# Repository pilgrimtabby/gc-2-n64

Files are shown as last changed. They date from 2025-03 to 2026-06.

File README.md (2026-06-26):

# gc-2-n64

PCB and custom firmware for a gamecube to N64 controller adapter. The firmware is an updated version of [Raphaël Assenat's](https://github.com/raphnet)'s v2.1 gc_to_n64 software ([here](https://www.raphnet.net/electronique/gc_to_n64/index_en.php), see also [here](https://github.com/raphnet/gc_to_n64)). It implements two major new features: an input viewer (from the USB port on the Arduino, compatible with RetroSpy) and a notch calibrator (heavily adapted from [Zenith Labs' algorithm](https://github.com/ZenithControlLabs/Zenith_FW)). It also allows many more degrees of flexibility when configuring soft triggers -- triggers can be mapped at 5% press, 10% press, 15% press, and so on until 100%. 

I have also included a file ([generate-button-map.html](generate-button-map.html)) that allows users to generate custom button mappings locally. Download the file and run it in a web browser to use it.

The PCB design was heavily inspired by and drawn from [SuperSpongo's DIY adapter design](https://circuit-board.de/forum/index.php/Thread/28130-Raphnets-GameCube-Controller-to-N64-Adapter-v2/). And as mentioned before, the credit for 99% of the ideas and code goes to Raphnet, Zenith Labs, and SuperSpongo. Because I modified firmware licensed under the GPLv3 License, the code in src/ is licensed under the GPLv3 License. The PCB is licensed under the MIT license.

# Instructions

## Assembly

This project requires an Arduino Nano (though I believe any Arduino running at 5V/16MHz should work) and a DC-DC 2V-24V to 5V-28V step-up converter (the N64 provides 3.3V and we need 5V to power the Gamecube controller). You'll also need a 1KΩ resistor (R4 on the schematic), two 22Ω resistors (R1 and R3), a 220Ω resistor (R2), an LED (D1), a male N64 controller port / cable, and a female Gamecube port / cable.

(Note: If you want to modify the KiCad files, you'll need the schematic and footprint files for the boost converter found [here](pcb/kicad/gc_2_n64/boost-converter-files)).

The step-up converter needs to be calibrated to output exactly 5V when receiving 3.3V. You can do this by connecting it to a 3.3V source, such as the N64, then turning the screw on the side until the output is correct.

When soldering the wires from the Gamecube in and N64 out, follow the labels in this image:

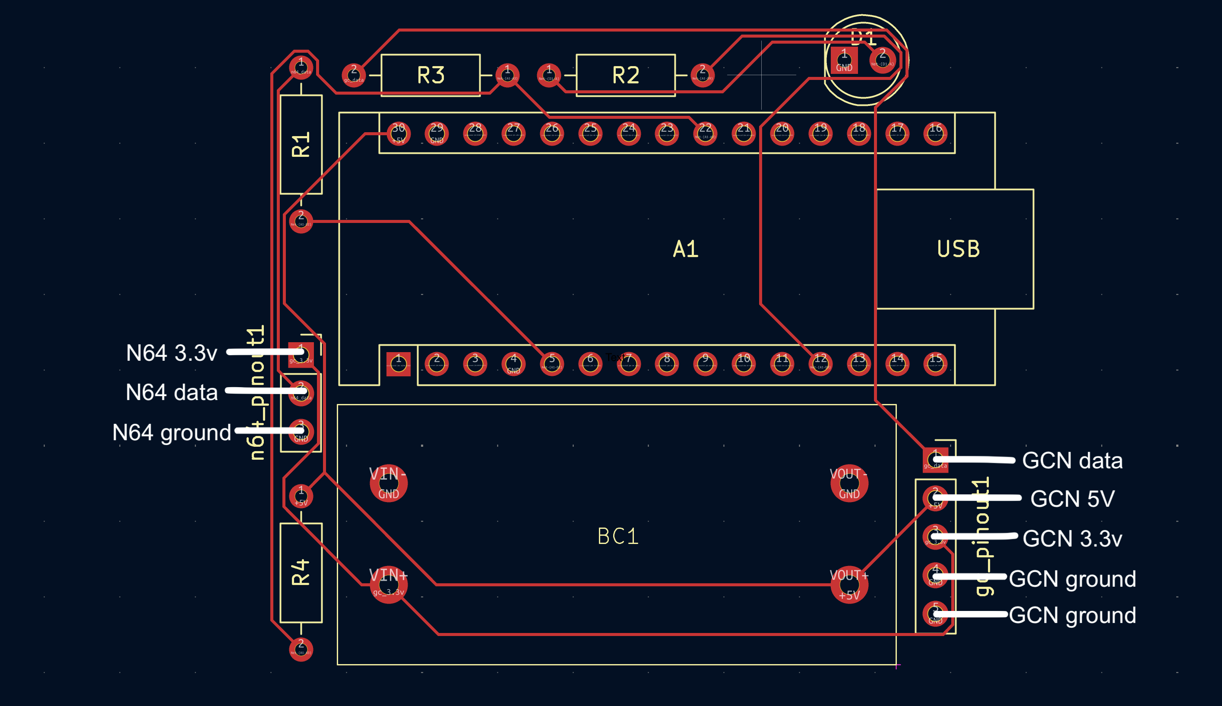
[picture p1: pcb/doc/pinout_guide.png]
Pinout guide


For the N64 pinout, see [here](https://consolemods.org/wiki/N64:Connector_Pinouts). Generally, the red cable is power, white is data, and black is ground.

Gamecube pinouts are all over the place depending on which vendor you purchase from. The best resource I am aware of is [this one](https://docs.google.com/spreadsheets/d/1X-F21F838uQRCuYsc7nQoAv6I2dchvXtBSNTf-ZOc9M).

## Example of Finished Project

The assembled PCB:

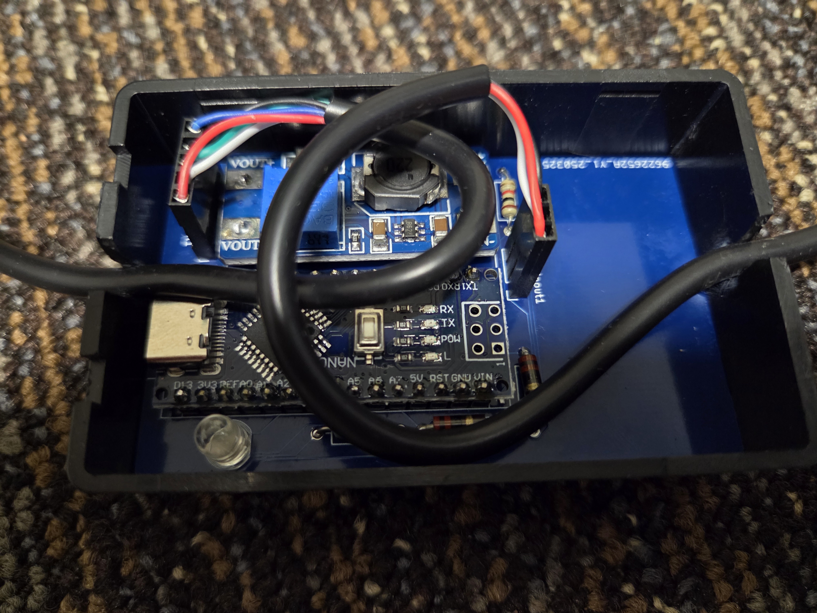
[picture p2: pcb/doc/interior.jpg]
Assembled PCB


The LED indicator:

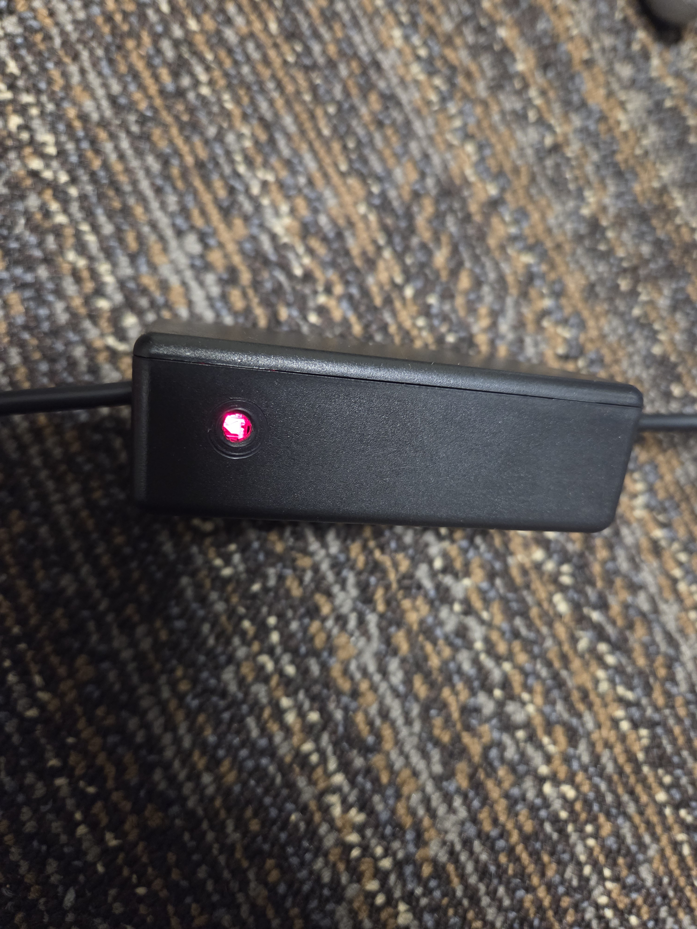
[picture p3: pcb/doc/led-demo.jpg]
LED light


Final product:

Completed project

## Flashing

To flash the Arduino, you will need [avrdude](https://github.com/avrdudes/avrdude) and the latest gc_2_n64.hex hexfile (see [Releases](https://github.com/pilgrimtabby/gc-2-n64/releases)). I successfully flashed the firmware using this command:

```
/path/to/avrdude /path/to/avrdude.conf -v -V -p atmega328p -c arduino -P /path/to/serial/port -b115200 -D -U flash:w:/path/to/hexfile
```

The path to the serial port can be obtained from the [Arduino IDE](https://www.arduino.cc/en/software/).

For detailed usage of the firmware, see Raphnet's [instructions](https://www.raphnet.net/electronique/gc_to_n64/index_en.php#8). To use the new input display, just connect the Arduino to your PC via the Arduino's USB port. To use the notch calibrator, hold down the start button for 8 seconds to access the menu, then press R, then press Y. Leave the control stick at neutral and press A. The LED will blink. Do the same thing for the eight notches, starting with straight up and moving clockwise around the gate. The mapping will be saved between sessions. To clear it, press A in the R menu.

Questions, issues, PRs, etc. more than welcome!

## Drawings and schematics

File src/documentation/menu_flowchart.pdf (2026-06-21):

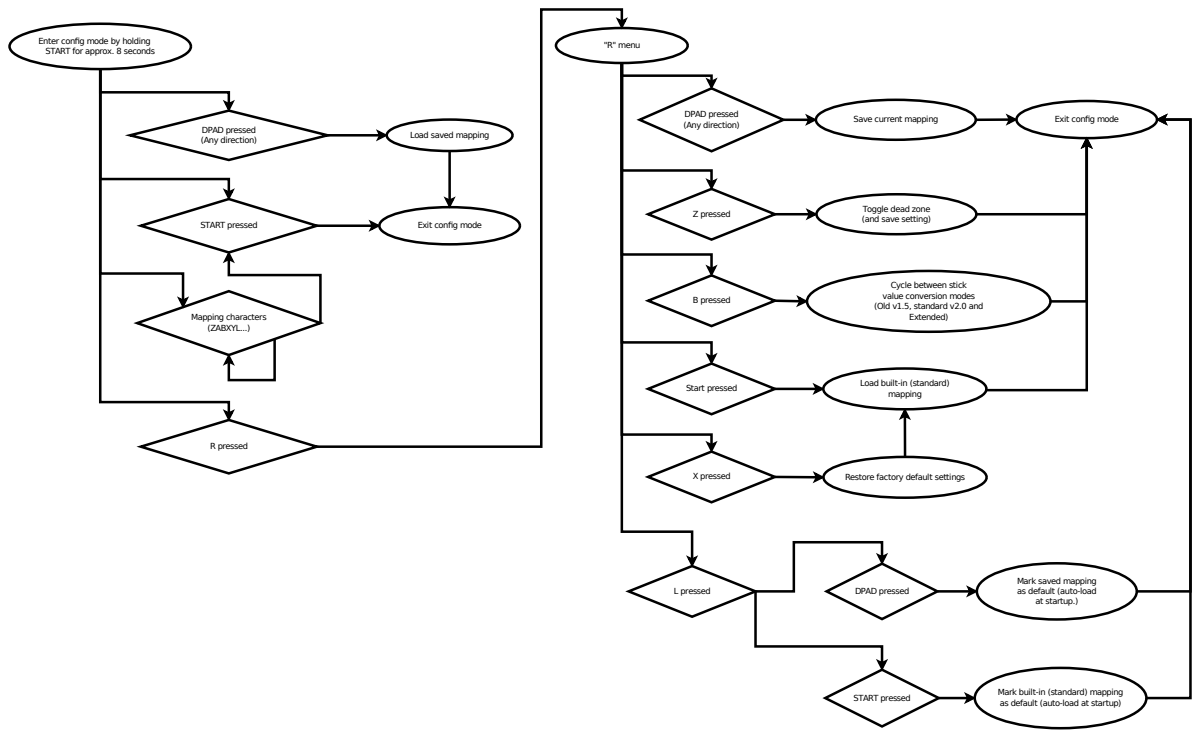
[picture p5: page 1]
DPAD pressed; (Any direction); Load saved mapping; START pressed; Exit config mode; Mapping characters (ZABXYL...); R pressed; "R" menu; Save current mapping; Z pressed; Toggle dead zone; Start pressed; Load built-in (standard); mapping; L pressed; B pressed; Extended); X pressed; Restore factory default settings

Enter config mode by holding
START for approx. 8 seconds

(and save setting)

Cycle between stick
value conversion modes
(Old v1.5, standard v2.0 and

Mark saved mapping
as default (auto-load
at startup.)

Mark built-in (standard) mapping
as default (auto-load at startup)

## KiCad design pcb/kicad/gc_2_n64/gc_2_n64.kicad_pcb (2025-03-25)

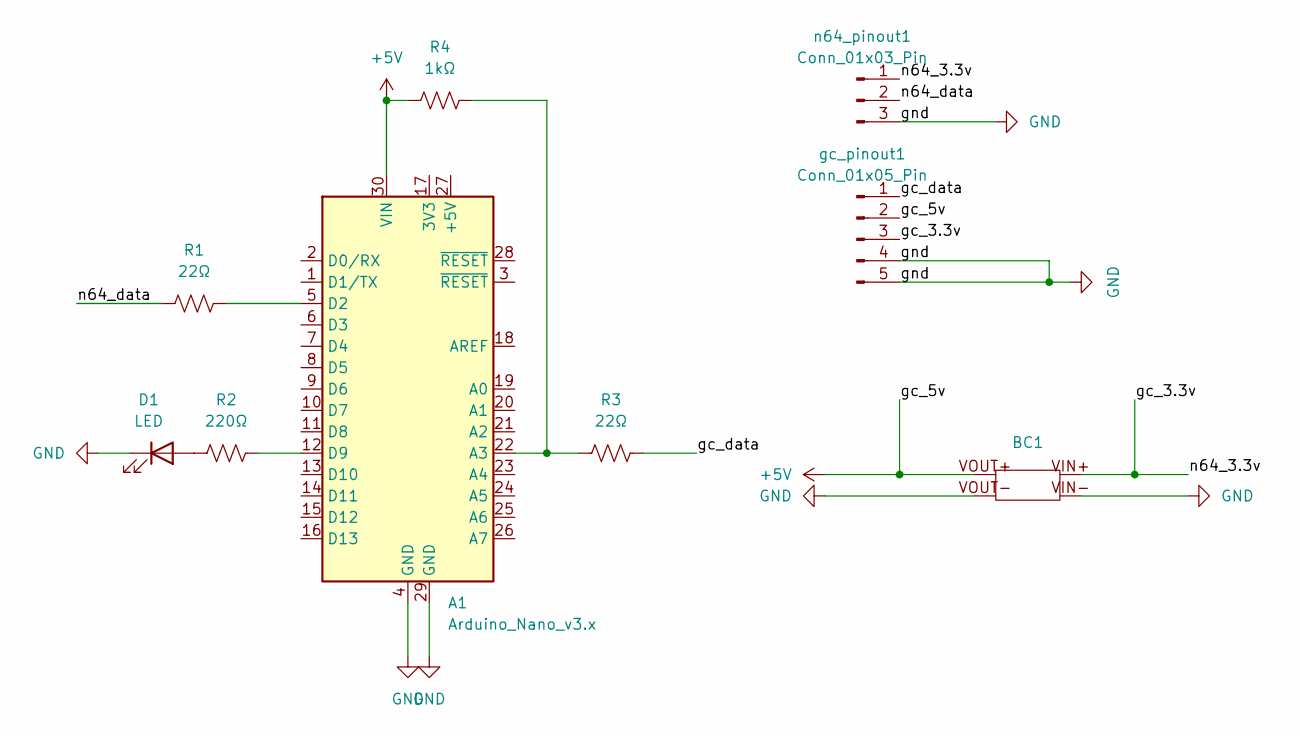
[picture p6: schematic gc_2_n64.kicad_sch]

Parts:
A1: Arduino_Nano_v3.x; Arduino_Nano
BC1: BC_boost_converter_MT3608_breakout
D1: LED; LED_D5.0mm
R1, R3: 22Ω; R_Axial_DIN0207_L6.3mm_D2.5mm_P10.16mm_Horizontal
R2: 220Ω; R_Axial_DIN0207_L6.3mm_D2.5mm_P10.16mm_Horizontal
R4: 1kΩ; R_Axial_DIN0207_L6.3mm_D2.5mm_P10.16mm_Horizontal
gc_pinout1: Conn_01x05_Pin; PinSocket_1x05_P2.54mm_Vertical
n64_pinout1: Conn_01x03_Pin; PinSocket_1x03_P2.54mm_Vertical

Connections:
+5V: A1.30 (VIN), BC1.VOUT+, R4.1, gc_pinout1.2
/gc_3.3v: BC1.VIN+, gc_pinout1.3, n64_pinout1.1
/gc_data: R3.2, gc_pinout1.1
/n64_data: R1.1, n64_pinout1.2
GND: A1.4 (GND), A1.29 (GND), BC1.VIN-, BC1.VOUT-, D1.1 (K), gc_pinout1.4, gc_pinout1.5, n64_pinout1.3
unnamed: A1.22 (A3), R3.1, R4.2
unnamed: A1.5 (D2), R1.2
unnamed: A1.12 (D9), R2.2
unnamed: D1.2 (A), R2.1

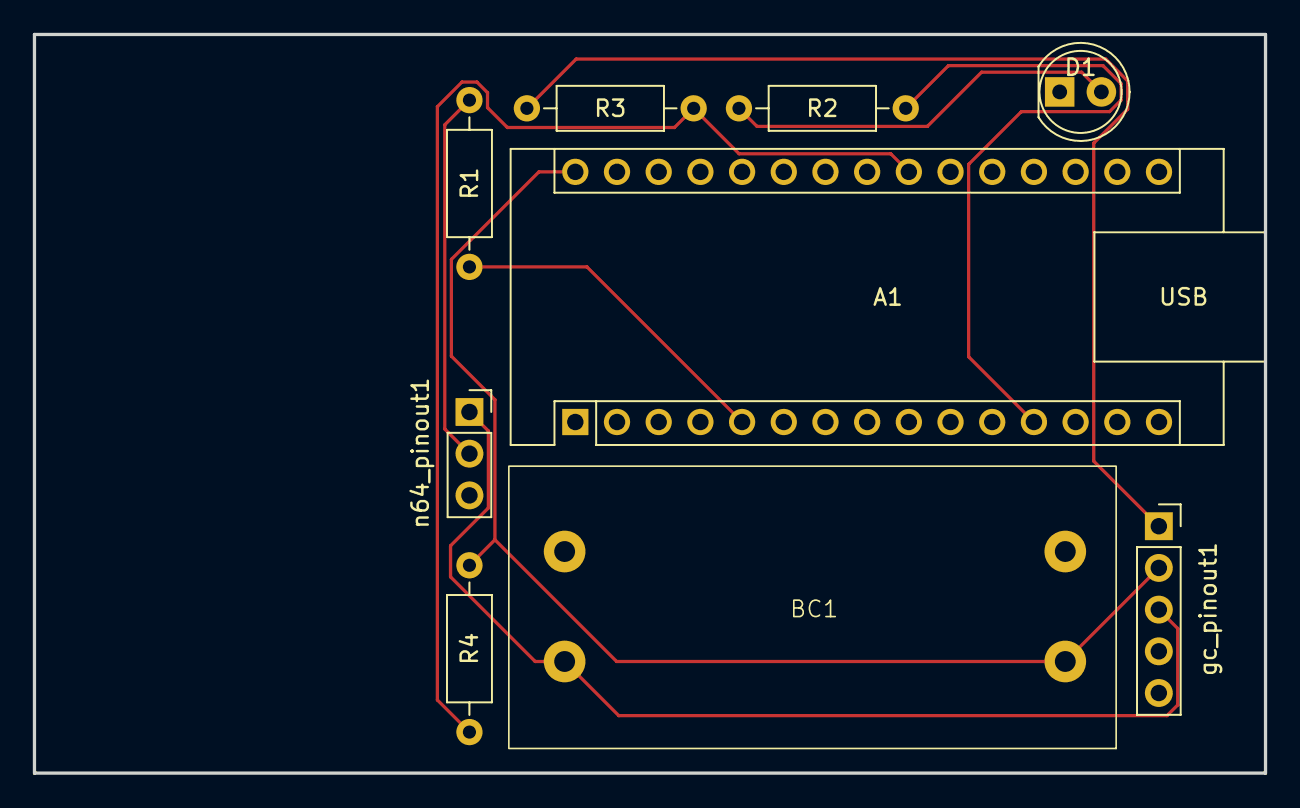
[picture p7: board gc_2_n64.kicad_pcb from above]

Board: 2 copper layers, 75.0 x 45.0 mm, 9 parts (0 on the bottom side), 9 nets.

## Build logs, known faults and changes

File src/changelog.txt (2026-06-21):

June 21, 2026: Pilgrim Tabby Version 1.0
    - Add notch calibration feature in R-menu
    - Add input display via Arduino's USB-C port, compatible with RetroSpy

April 9, 2017 : Version 2.1
    - Add a new conversion mode for Joystick values: Extended (where Gamecube
  	  values are forwarded to the N64 without transformations)
    - Set lock bits to protect bootloader from erasure

October 10, 2015 : Version 2.0
    - Now built for Atmega168 by default. Old makefile for Atmega8 is still available.
	- Add a bootloader (Atmega168 only) for software updates.
    - N64 communication code improvements (more reliable. Fixes the F-Zero X bug!)
    - Improved joystick value conversion (the old behaviour is available via a menu option).
	- Add a reset to factory defaults function.
	- Add mapping load/save through the N64 interface support
	- Add visual buzzer (simple LED) support. (default for Atmega168)
    - Created a flowchart of the menu

March 15, 2015 : Version 1.5.1
    - New fuse values to enable brown out detector. Fixes
	  the issue of random loss of mappings.

February 7, 2015 : Version 1.5
    - Add a feature to select the default mapping at startup.
	- Minor updates for compilation with recent toolchain.

May 5, 2013 : Version 1.4
    - Tighter timing in the N64 interrupt handler. The adapter now
	  starts answering much faster. This appears to fix F-Zero X.
	  (Never seen a game picky and *buggy like that)
	  * Disconnect even a standard controller and say goodbye
	  to your race. Connecting the controller back does not work. Right,
	  no reason to do that. But if the controller fails to answer only
	  one poll request, it's game over...
    - Fix an ED64 menu "freeze" bug
	- Improve the Wavebird neutral position

April 27, 2013 : Version 1.3.1
    - Fixed a bug when mapping the main joystick to buttons.
	  The up[18]/down[19] and left[20]/right[21] directions were inverted.
    - Fixed a bug when entering a new mapping code where the unchanged
 	  parts of the previously active mapping remained in effect.

March 2, 2013 : Version 1.3
    - Added a joystick deadzone feature (default OFF). To enable,
	or disable if previously enabled, hold START until your hear the 5
	beeps, fully press and release R, the press Z. Wait a few moments
	for the final beeps. The setting is stored in the adapter, no need
	 to repeat after each power up.

February 12, 2013 : Version 1.2.2 - Bug fixes and minor features
    - The analog L and R sliders are now unmapped by default.
    - Beep on read errors (when disconnecting controller).
    - Beep once at powerup.

July 31, 2012 : Version 1.2.1 - Quick bug fix
    - Reset the read failure counter on success. Otherwise the failures
	  accumulate and eventually forces a recalibration, potentially in-game.

July 30, 2012 : Version 1.2 - Bug fixes and maintenance

	- Auto-calibration is now done each time a new controller
	  is connected, which means controllers can be swapped at runtime.
	- The above makes the Wavebird work properly again (was broken in v1.1!)
	- At powerup, the adapter waits for a Gamecube controller.
	- A newer version of the Gamecube communication code (ported from my
	  N64/Gamecube to USB project) is now in place.

January 25, 2011 : Version 1.1. Compatiblity fixes:

    - Auto-calibration of the gamecube joystick at powerup fixes
	  compatiblity issues with controllers that are not *perfectly*
	  centered.

	- Better conversion from Gamecube axis values to N64 values. This
	  fixes issues with some game/controllers where, for instance,
	  the character would not run at full speed.

	Note: The maximum axis values and corner angles closely approximates
    those from a N64 Hori mini pad.

August 10, 2011 : Version 1.0. Initial relase.

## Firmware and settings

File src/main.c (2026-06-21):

/*  GC to N64 : Gamecube controller to N64 adapter firmware
    Copyright (C) 2011-2017  Raphael Assenat <raph@raphnet.net>

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
    You should have received a copy of the GNU General Public License
    along with this program.  If not, see <http://www.gnu.org/licenses/>.
*/

// Modified by Pilgrim Tabby (2026) to add new mapping options

#include <stdio.h>
#include <string.h>
#include <stdlib.h>
#include <util/delay.h>
#include <avr/io.h>
#include <avr/interrupt.h>
#include <avr/pgmspace.h>
#include "main.h"
#include "buzzer.h"
#include "timer0.h"
#include "lut.h"
#include "menu.h"

#include "gamecube.h"

//#include "gc_offsets.h"
//#include "n64_offsets.h"

#include "n64_isr.h"
#include "sync.h"
#include "mapper.h"
#include "gamecube_mapping.h"
#include "n64_mapping.h"
#include "compat.h"
#include "eeprom.h"
#include "retrospy.h"
#include "notch_cal.h"

/* After this many read failures in a row, consider the controller
 * gone and wait for a new one. (whose first read will be considered
 * the origin) */
#define READ_FAIL_LIMIT		20

#define DEBUG_LOW()		do { PORTD &= ~(1); } while(0)
#define DEBUG_HIGH()	do { PORTD |= 1; } while(0)

#ifdef AT168_COMPATIBLE
/* This is just a constant that will be in flash. The update tool will search
 * the hexfile for this sequence. In not found, update won't take place. The
 * goal is to prevent temporary bricking due to users using the wrong .hex.   */
const char signature[] PROGMEM = "41d938a8-6f8a-11e5-a45e-001bfca3c593";

/* This marker is used by the bootloader to protect against partial programming.
 * Since programming is done with increasing addresses, if it is interrupted, this
 * sequence at the end will be missing if interrupted. */
const char endmarker[4] __attribute__((section(".endmarker")))  = { 0x12, 0x34, 0x56, 0x78 };
#endif

void enter_bootloader(void);

Gamepad *g_gcpad;
unsigned char gc_report[GC_REPORT_SIZE];

// When non-zero, triggers saving the current mapping to specified slot
// in the main loop.
static volatile unsigned char g_todo_save_mapping;

struct mapping_entry current_mapping[MAP_GC_NONE + 2];

struct mapping_entry gamecube_to_n64_default_mapping[MAP_GC_NONE + 2] = {
	{ MAP_GC_BTN_A,				MAP_N64_BTN_A },
	{ MAP_GC_BTN_B,				MAP_N64_BTN_B },
	{ MAP_GC_BTN_Z,				MAP_N64_BTN_Z },
	{ MAP_GC_BTN_START,			MAP_N64_BTN_START },
	{ MAP_GC_BTN_L,				MAP_N64_BTN_L },
	{ MAP_GC_BTN_R,				MAP_N64_BTN_R },
	{ MAP_GC_AXB_C_UP,			MAP_N64_BTN_C_UP },
	{ MAP_GC_AXB_C_DOWN,		MAP_N64_BTN_C_DOWN },
	{ MAP_GC_AXB_C_LEFT,		MAP_N64_BTN_C_LEFT },
	{ MAP_GC_AXB_C_RIGHT,		MAP_N64_BTN_C_RIGHT },
	{ MAP_GC_BTN_DPAD_UP,		MAP_N64_BTN_DPAD_UP },
	{ MAP_GC_BTN_DPAD_DOWN,		MAP_N64_BTN_DPAD_DOWN },
	{ MAP_GC_BTN_DPAD_LEFT,		MAP_N64_BTN_DPAD_LEFT },
	{ MAP_GC_BTN_DPAD_RIGHT,	MAP_N64_BTN_DPAD_RIGHT },
	{ MAP_GC_AXIS_LEFT_RIGHT,	MAP_N64_AXIS_LEFT_RIGHT },
	{ MAP_GC_AXIS_UP_DOWN,		MAP_N64_AXIS_UP_DOWN },
	{ MAP_GC_BTN_X,				MAP_N64_NONE },
	{ MAP_GC_BTN_Y,				MAP_N64_NONE },
	{ MAP_GC_AXB_JOY_UP,		MAP_N64_NONE },
	{ MAP_GC_AXB_JOY_DOWN,		MAP_N64_NONE },
	{ MAP_GC_AXB_JOY_LEFT,		MAP_N64_NONE },
	{ MAP_GC_AXB_JOY_RIGHT,		MAP_N64_NONE },
	{ MAP_GC_AXIS_C_LEFT_RIGHT,	MAP_N64_NONE },
	{ MAP_GC_AXIS_C_UP_DOWN,	MAP_N64_NONE },

	/* These slots must exist (even pointing at MAP_N64_NONE) for
	 * mapper_change_mapping_entry() to find and overwrite them via
	 * the menu code system. It only updates existing entries, it
	 * never inserts new ones. */
	{ MAP_GC_L_05,  MAP_N64_NONE },
	{ MAP_GC_L_10,  MAP_N64_NONE },
	{ MAP_GC_L_15,  MAP_N64_NONE },
	{ MAP_GC_L_20,  MAP_N64_NONE },
	{ MAP_GC_L_25,  MAP_N64_NONE },
	{ MAP_GC_L_30,  MAP_N64_NONE },
	{ MAP_GC_L_35,  MAP_N64_NONE },
	{ MAP_GC_L_40,  MAP_N64_NONE },
	{ MAP_GC_L_45,  MAP_N64_NONE },
	{ MAP_GC_L_50,  MAP_N64_NONE },
	{ MAP_GC_L_55,  MAP_N64_NONE },
	{ MAP_GC_L_60,  MAP_N64_NONE },
	{ MAP_GC_L_65,  MAP_N64_NONE },
	{ MAP_GC_L_70,  MAP_N64_NONE },
	{ MAP_GC_L_75,  MAP_N64_NONE },
	{ MAP_GC_L_80,  MAP_N64_NONE },
	{ MAP_GC_L_85,  MAP_N64_NONE },
	{ MAP_GC_L_90,  MAP_N64_NONE },
	{ MAP_GC_L_95,  MAP_N64_NONE },
	{ MAP_GC_L_100, MAP_N64_NONE },

	{ MAP_GC_R_05,  MAP_N64_NONE },
	{ MAP_GC_R_10,  MAP_N64_NONE },
	{ MAP_GC_R_15,  MAP_N64_NONE },
	{ MAP_GC_R_20,  MAP_N64_NONE },
	{ MAP_GC_R_25,  MAP_N64_NONE },
	{ MAP_GC_R_30,  MAP_N64_NONE },
	{ MAP_GC_R_35,  MAP_N64_NONE },
	{ MAP_GC_R_40,  MAP_N64_NONE },
	{ MAP_GC_R_45,  MAP_N64_NONE },
	{ MAP_GC_R_50,  MAP_N64_NONE },
	{ MAP_GC_R_55,  MAP_N64_NONE },
	{ MAP_GC_R_60,  MAP_N64_NONE },
	{ MAP_GC_R_65,  MAP_N64_NONE },
	{ MAP_GC_R_70,  MAP_N64_NONE },
	{ MAP_GC_R_75,  MAP_N64_NONE },
	{ MAP_GC_R_80,  MAP_N64_NONE },
	{ MAP_GC_R_85,  MAP_N64_NONE },
	{ MAP_GC_R_90,  MAP_N64_NONE },
	{ MAP_GC_R_95,  MAP_N64_NONE },
	{ MAP_GC_R_100, MAP_N64_NONE },

	{ MAP_GC_NONE,				MAP_N64_NONE },
	{ -1, -1 }, // terminator
};

void saveCurrentMappingTo(int id)
{
	if (id >= 1 && id <= 4) {
		memcpy( g_eeprom_data.appdata + (sizeof(current_mapping) * (id-1)), current_mapping, sizeof(current_mapping));
		eeprom_commit();
	}
}

int loadMappingId(int id)
{
	unsigned char *mapping_pointer;

	// Always start from default mapping
	memcpy(current_mapping, gamecube_to_n64_default_mapping, sizeof(current_mapping));

	switch(id)
	{
		default:
		case 0:
			// default mapping used.
			break;

		case 1:
		case 2:
		case 3:
		case 4:
			mapping_pointer = g_eeprom_data.appdata + (sizeof(current_mapping) * (id-1));
			if (mapping_pointer[0] == 0xff) {
				// Terminator at the beginning? Empty slot!
				return -1;
			}
			memcpy(current_mapping, mapping_pointer, sizeof(current_mapping));
	}
	return 0;
}


int domenu(struct mapping_controller_unit *gcs)
{
	static int start_seconds = 0;

	if (gcs[MAP_GC_BTN_START].value) 
	{
		if (timerIsOver()) {
			start_seconds++;
			if (start_seconds > 5) {
				menumain();
				return 1;
			}
		} 
	}
	else {
		start_seconds = 0;
	}
	return 0;
}
void byteTo8Bytes(unsigned char val, unsigned char volatile *dst)
{
	unsigned char c = 0x80;

	do {
		*dst = val & c;
		dst++;
		c >>= 1;
	} while(c);
}


#define IS_ACTIVE(a) ((a).value != (a).def)

unsigned char long_command_handler(unsigned char len)
{
	if (len >= 2)
	{
		if (g_n64_buf[0] == 'R') {
			switch (g_n64_buf[1]) {
				case 0x00: // echo
					return len;

				case 0x01: // Get info
					memset((void*)g_n64_buf, 0, sizeof(g_n64_buf));
					g_n64_buf[0] = 0; // Isbootloader? No.
					g_n64_buf[1] = g_eeprom_data.defmap;
					g_n64_buf[2] = g_eeprom_data.deadzone_enabled;
					g_n64_buf[3] = g_eeprom_data.old_v1_5_conversion;
					g_n64_buf[4] = g_eeprom_data.conversion_mode;
#ifdef AT168_COMPATIBLE
					g_n64_buf[9] = 1; // Upgradable
#endif
					strcpy((void*)(g_n64_buf+10), VERSION_STR);
					return 10 + strlen(VERSION_STR) + 1;

				case 0x02: // Get mapping
					if (len >= 4) {
						int id = g_n64_buf[2];
						int chunk = g_n64_buf[3];
						unsigned short mapping_size = sizeof(current_mapping);

						if (id >= 0 && id <= 4) {
							unsigned char *mapping_pointer;

							if (id) {
								mapping_pointer = g_eeprom_data.appdata + (sizeof(current_mapping) * (id-1));
							} else {
								mapping_pointer = (unsigned char*)&current_mapping[0];
							}

							if (chunk == 0) {
                                g_n64_buf[0] = mapping_size & 0xff;
                                return 1;
                            } else {
                                int offset = (chunk - 1) * 32;
                                if (offset >= mapping_size) return 0;
                                
                                int to_copy = mapping_size - offset;
                                if (to_copy > 32) to_copy = 32;
                                
                                memcpy((void*)g_n64_buf, mapping_pointer + offset, to_copy);
                                return to_copy;
                            }

							return 0;
						}
					}
					break;

				case 0x03: // Set mapping
                    if (len > 3) {
                        int chunk = g_n64_buf[2];
                        unsigned char *mapping_pointer = (unsigned char*)&current_mapping[0];
                        
                        /* In 'Set' commands, chunks are 0-indexed. 
                           Chunk 0 = offset 0, Chunk 1 = offset 32, etc. */
                        int offset = chunk * 32;

                        /* If it is the very first chunk, wipe the old mapping clean */
                        if (offset == 0) {
                            memset(mapping_pointer, 0xff, sizeof(current_mapping));
                        }

                        /* Safely copy the incoming data into the array */
                        if (offset < sizeof(current_mapping)) {
                            int to_copy = len - 4;
                            
                            /* Ensure the incoming payload doesn't exceed array bounds */
                            if (offset + to_copy > sizeof(current_mapping)) {
                                to_copy = sizeof(current_mapping) - offset;
                            }
                            
                            memcpy(mapping_pointer + offset, (void*)(g_n64_buf+3), to_copy);
                        }
                        
                        return 1;
                    }
                    break;

				case 0x04: // Save current mapping
					if (len > 2) {
						int id = g_n64_buf[2];

						if (id < 1 || id > 4) {
							g_n64_buf[0] = 0x01; // NACK (out of range)
							return 1;
						}

						// This need to be done in the main loop. It takes
						// too much time and the host may timeout waiting
						// for an answer.
						//
						// Setting this to non-zero triggers a write. It gets
						// cleared back to 0 once it's done.
						//
						// The caller should poll the adapter for business
						// before sending this.
						g_todo_save_mapping = id;
						g_n64_buf[0] = 0x00;
						return 1; // ACK
					}
					break;

				case 0xf9:
					if (g_todo_save_mapping) {
						g_n64_buf[0] = 1;
					} else {
						g_n64_buf[0] = 0;
					}
					return 1;

#ifdef AT168_COMPATIBLE
				case 0xff:
					enter_bootloader();
					break;
#endif
			}
		}
	}
	return 0;
}

void packbytes(unsigned char *input, unsigned char volatile *output, int bytes)
{
	int i;
	unsigned char b;
	unsigned char tmp;

	for (i=0; i<bytes; i++) {
		for (tmp=0, b=0x80; b; b >>= 1) {
			if (*input) {
				tmp |= b;
			}
			input++;
		}
		*output = tmp;
		output++;
	}
}

void n64_status_to_output(struct mapping_controller_unit *n64s, unsigned char volatile output[4])
{
	char x,y;
	unsigned char dstbuf[32];

	dstbuf[0] = IS_ACTIVE(n64s[MAP_N64_BTN_A]);
	dstbuf[1] = IS_ACTIVE(n64s[MAP_N64_BTN_B]);
	dstbuf[2] = IS_ACTIVE(n64s[MAP_N64_BTN_Z]);
	dstbuf[3] = IS_ACTIVE(n64s[MAP_N64_BTN_START]);
	dstbuf[4] = IS_ACTIVE(n64s[MAP_N64_BTN_DPAD_UP]);
	dstbuf[5] = IS_ACTIVE(n64s[MAP_N64_BTN_DPAD_DOWN]);
	dstbuf[6] = IS_ACTIVE(n64s[MAP_N64_BTN_DPAD_LEFT]);
	dstbuf[7] = IS_ACTIVE(n64s[MAP_N64_BTN_DPAD_RIGHT]);
	dstbuf[8] = 0;
	dstbuf[9] = 0;
	dstbuf[10] = IS_ACTIVE(n64s[MAP_N64_BTN_L]);
	dstbuf[11] = IS_ACTIVE(n64s[MAP_N64_BTN_R]);
	dstbuf[12] = IS_ACTIVE(n64s[MAP_N64_BTN_C_UP]);
	dstbuf[13] = IS_ACTIVE(n64s[MAP_N64_BTN_C_DOWN]);
	dstbuf[14] = IS_ACTIVE(n64s[MAP_N64_BTN_C_LEFT]);
	dstbuf[15] = IS_ACTIVE(n64s[MAP_N64_BTN_C_RIGHT]);

	x = n64s[MAP_N64_AXIS_LEFT_RIGHT].value;
	y = n64s[MAP_N64_AXIS_UP_DOWN].value;

	if (IS_ACTIVE(n64s[MAP_N64_AXB_JOY_UP]))
		y = n64s[MAP_N64_AXB_JOY_UP].value;
	if (IS_ACTIVE(n64s[MAP_N64_AXB_JOY_DOWN]))
		y = n64s[MAP_N64_AXB_JOY_DOWN].value;
	if (IS_ACTIVE(n64s[MAP_N64_AXB_JOY_LEFT]))
		x = n64s[MAP_N64_AXB_JOY_LEFT].value;
	if (IS_ACTIVE(n64s[MAP_N64_AXB_JOY_RIGHT]))
		x = n64s[MAP_N64_AXB_JOY_RIGHT].value;

	byteTo8Bytes(x, dstbuf + 16);
	byteTo8Bytes((y)^0xff, dstbuf + 24);

	packbytes(dstbuf, output, 4);
}

int main(void)
{
	char res, read_fail_count = 0;

	/* Shadow copy of the last N64 output; sent via RetroSpy every cycle. */
	static unsigned char retrospy_shadow[4] = { 0, 0, 0x80, 0x80 };

	g_gcpad = gamecubeGetGamepad();


	// PORTD2 is the N64 data signal.
	// Pullup resistors on all other signals.
	//
	DDRD=0;
	PORTD |= ~0x04;

	// portD 0 is debug bit
	DDRD |= 1;

	// temporary
	DDRC=0;
	PORTC=0xff;

#ifdef AT168_COMPATIBLE
	EICRA = 0x02;
	EIMSK = 0x01;
#else
	// configure external interrupt 1 to trigger on falling edge.
	MCUCR |= 1<<ISC11;
	MCUCR &= ~(1<<ISC10);

	GICR |= (1<<INT0);
#endif

	memset((void*)n64_tx_buf0, 0, sizeof(n64_tx_buf0));
	memset((void*)n64_tx_buf1, 0, sizeof(n64_tx_buf1));

	// Set answer to 0x05 0x00 0x02
	n64_tx_id_reply[0] = 0x05;
	n64_tx_id_reply[1] = 0x00;
	n64_tx_id_reply[2] = 0x02;

	buzzer_init();
	blips(1);

	if (eeprom_init()) {
		/* This is to test the buzzer right
		 * after programming completes. The next time
		 * the board powers up the buzzer will be
		 * silent, unless the eeprom got corrupted. */
		blips(2);
	}

	/* Initialise RetroSpy serial output (USART0, 115200 baud). */
	retrospy_init();

	/* Load notch calibration from EEPROM (passthrough if none saved). */
	notch_cal_init();


	sei();

	loadMappingId(g_eeprom_data.defmap);

	timerStart();

	g_gcpad->init();

	DEBUG_HIGH();
	_delay_ms(500);

	/* Read from Gamecube controller. As long as this fails,
	 * keep trying. We need the initial read to use as origin
	 * position. */
wait_for_controller:
	while (0 != (res = g_gcpad->update(GAMECUBE_UPDATE_ORIGIN))) {
		_delay_ms(16);
	}
	read_fail_count = 0;

	g_gcpad->buildReport(gc_report);

	// Learn the joystick origin to use
	_delay_ms(16);
	setOriginsFromReport(gc_report);

	gc_report_to_mapping(gc_report, g_gamecube_status);


	if (g_gamecube_status[MAP_GC_BTN_START].value) {
		menumain(g_gamecube_status);
	}

	DEBUG_LOW();

	sync_init();

	while(1)
	{
		if (n64_got_command) {
			n64_got_command = 0;
			sync_master_polled_us();
		}

		if (g_todo_save_mapping) {
			saveCurrentMappingTo(g_todo_save_mapping);
			g_todo_save_mapping = 0;
		}

		if (sync_may_poll()) {
			DEBUG_HIGH();
			timerIntOff();
			res = g_gcpad->update(GAMECUBE_UPDATE_NORMAL);
			timerIntOn();
			DEBUG_LOW();

			if (res) {
				read_fail_count++;
				if (read_fail_count > READ_FAIL_LIMIT) {
					blips(1);
					goto wait_for_controller;
				}
			} else {
				read_fail_count = 0;
			}

			if (g_gcpad->changed()) {
				DEBUG_HIGH();
				// Read the gamepad
				g_gcpad->buildReport(gc_report);

				// Convert the data we got from the gamepad reader
				// to a mapping structure.
				gc_report_to_mapping(gc_report, g_gamecube_status);

				// Maybe enter configuration menu mode. If we did,
				// 1 is returned.

				// Perform mapping (conversion), copying data at appropriate
				// places in the output structure (n64 status)
				mapper_copy(current_mapping, g_gamecube_status, g_n64_status);

				// Convert the N64 status mapping structure to a raw buffer we can send
				// to the console in interrupt context.
				{
					volatile unsigned char *dst = n64_use_buf1 ? n64_tx_buf0 : n64_tx_buf1;
					n64_status_to_output(g_n64_status, dst);

					/* Update the RetroSpy shadow copy atomically. */
					retrospy_shadow[0] = dst[0];
					retrospy_shadow[1] = dst[1];
					retrospy_shadow[2] = dst[2];
					retrospy_shadow[3] = dst[3];
				}

				n64_use_buf1 = !n64_use_buf1;
				DEBUG_LOW();
			}

			domenu(g_gamecube_status);

			/*
			 * Send the current state to RetroSpy on every poll cycle
			 * (regardless of whether the controller state changed) so
			 * the PC application receives a continuous stream.
			 * At 115200 baud, 33 bytes takes ~2.9 ms, well within the
			 * ~16 ms N64 polling interval.
			 */
			retrospy_send(retrospy_shadow);

		}
	}
}

void enter_bootloader(void)
{
	cli();
	// Make sure timer interrupt is not kept
	timerIntOff();
	asm volatile("ijmp" :: "z" (0x1C00));
}

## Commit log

2025-03-25 Add gerber files
    [gc_2_n64-B_Cu.gbl, gc_2_n64-B_Mask.gbs, gc_2_n64-B_Paste.gbp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]
2025-03-25 Update README, add KiCad files
    [gc_2_n64.kicad_pcb, gc_2_n64.kicad_sch]
2026-06-21 Add custom firmware
    I adapted Raphnet's 2.1 firmware to add customizable triggers, notch calibration, and an input viewer. The makefile has also been updated to specifically target the 328P architecture, siince the soft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
    [gc_2_n64-B_Cu.gbl, gc_2_n64-B_Mask.gbs, gc_2_n64-B_Paste.gbp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]
2026-06-21 Update README with licensing details
    Added licensing information for firmware and PCB
2026-06-21 Add button mapping generator html file
    This file can be loaded in a web browser to create button mappings.

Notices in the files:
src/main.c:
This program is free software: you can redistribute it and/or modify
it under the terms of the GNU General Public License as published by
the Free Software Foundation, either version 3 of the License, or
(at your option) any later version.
